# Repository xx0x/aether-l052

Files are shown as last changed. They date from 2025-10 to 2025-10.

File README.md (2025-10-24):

# Æther L052

A development board using the STM32L052K8Ux, optimized for low-power use. Its form factor matches the Adafruit Feather series.

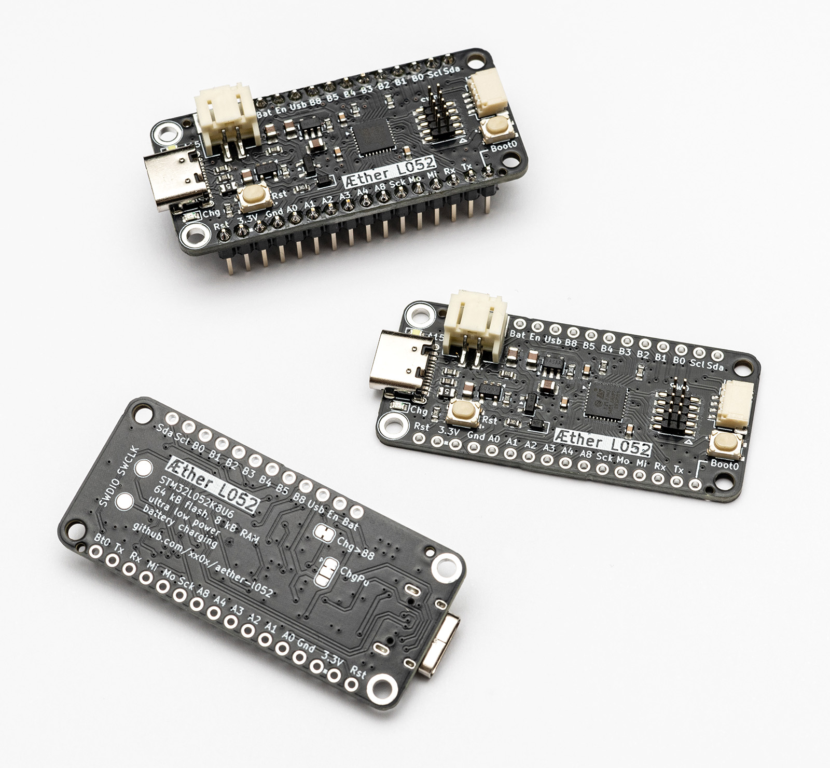
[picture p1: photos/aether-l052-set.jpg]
Aether L052


## Schematic

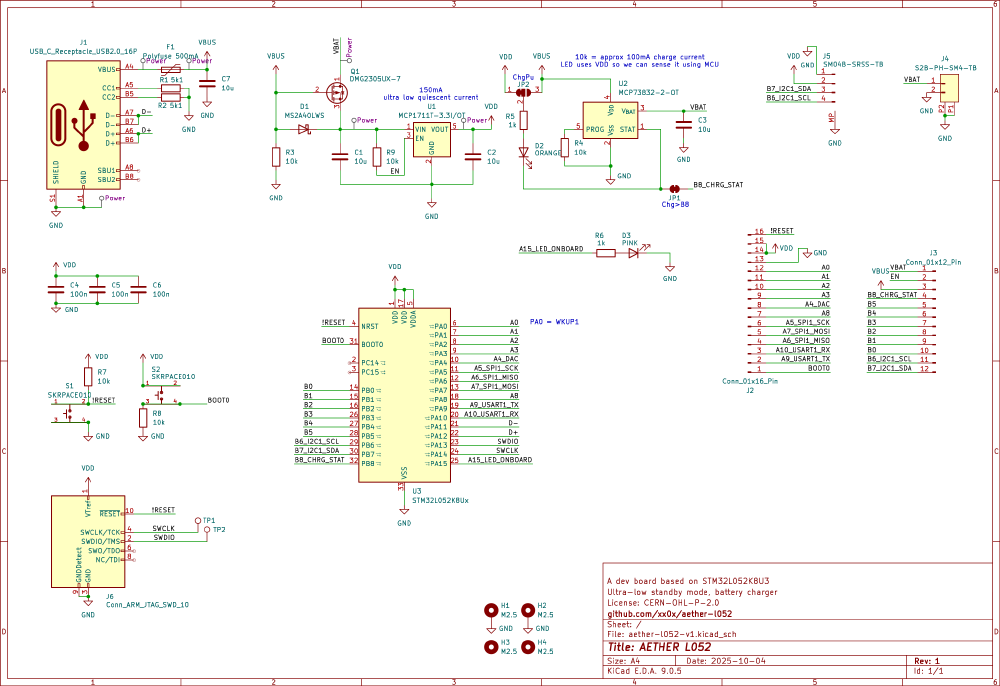
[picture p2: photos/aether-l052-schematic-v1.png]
Aether L052
  
*Click to see the full-size PDF*

## Specifications

### Microcontroller

| Name | STM32L052K8Ux |
| --- | --- |
| Core | ARM Cortex M0+ |
| Flash Size | 64 kB |
| RAM Size | 8 kB |
| Clock Frequency  | 32 MHz |
| Peripherals | USB, SPI, I2C, UART |
| External Crystal | None |

STM32L052K8U6 = –40 to 85 °C  
STM32L052K8U7 = –40 to 105 °C  
STM32L052K8U3 = –40 to 125 °C  

### Voltage Regulator

| Name | MCP1711T-33I/OT |
| --- | --- |
| Output Voltage | 3.3 V |
| Output Current | 150 mA |
| Quiescent Current | 600 nA |

### Lithium Battery Charger

| Name | MCP73832T-2ACI/OT |
| --- | --- |
| Charge Current | 100 mA (set using R4) |
| Charge State | Available through PB8 |

## Why it exists?

There was no entry-level development board for the STM32L052 series, especially for the compact STM32L052K8Ux variant.

## Where to get it?

Æther L052 is open source and not sold in shops. You can build your own; all required files are in the `pcb` folder. If you are a manufacturer, you may reuse the design under the License, or contact me first if you prefer.

## Code examples

Look at the [Æther L052 Examples](https://github.com/xx0x/aether-l052-examples) repository.

## License

CERN-OHL-P-2.0 license

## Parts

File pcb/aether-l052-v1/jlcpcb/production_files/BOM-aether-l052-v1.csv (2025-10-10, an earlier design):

Comment | Designator | Footprint | LCSC | Quantity
100n | C4,C5,C6 | C_0603_1608Metric | C14663 | 3
10k | R3,R4,R7,R8,R9 | R_0603_1608Metric | C25804 | 5
10u | C1,C2,C3,C7 | C_0805_2012Metric | C15850 | 4
1k | R5,R6 | R_0603_1608Metric | C21190 | 2
5k1 | R1,R2 | R_0603_1608Metric | C23186 | 2
Conn_ARM_JTAG_SWD_10 | J6 | PinHeader_2x05_P1.27mm_Vertical_SMD | C41376037 | 1
DMG2305UX-7 | Q1 | SOT-23 | C150470 | 1
MCP1711T-3.3I/OT | U1 | SOT-23-5 | C79527 | 1
MCP73832-2-OT | U2 | SOT-23-5 | C38066 | 1
MS2A40LWS | D1 | D_SOD-323 | C7380001 | 1
ORANGE | D2 | LED_0603_1608Metric | C2286 | 1
PINK | D3 | LED_0603_1608Metric | C2290 | 1
Polyfuse 500mA | F1 | Fuse_0805_2012Metric | C883109 | 1
S2B-PH-SM4-TB | J4 | S2B-PH-SM4-TB_LF__SN_ | C295747 | 1
SKRPACE010 | S1,S2 | SKRPACE010 | C139797 | 2
SM04B-SRSS-TB | J5 | JST_SH_SM04B-SRSS-TB_1x04-1MP_P1.00mm_Horizontal | C160404 | 1
STM32L052K8Ux | U3 | QFN-32-1EP_5x5mm_P0.5mm_EP3.45x3.45mm | C1342049 | 1
USB_C_Receptacle_USB2.0_16P | J1 | USB_C_Receptacle_XKB_U262-16XN-4BVC11 | C393939 | 1

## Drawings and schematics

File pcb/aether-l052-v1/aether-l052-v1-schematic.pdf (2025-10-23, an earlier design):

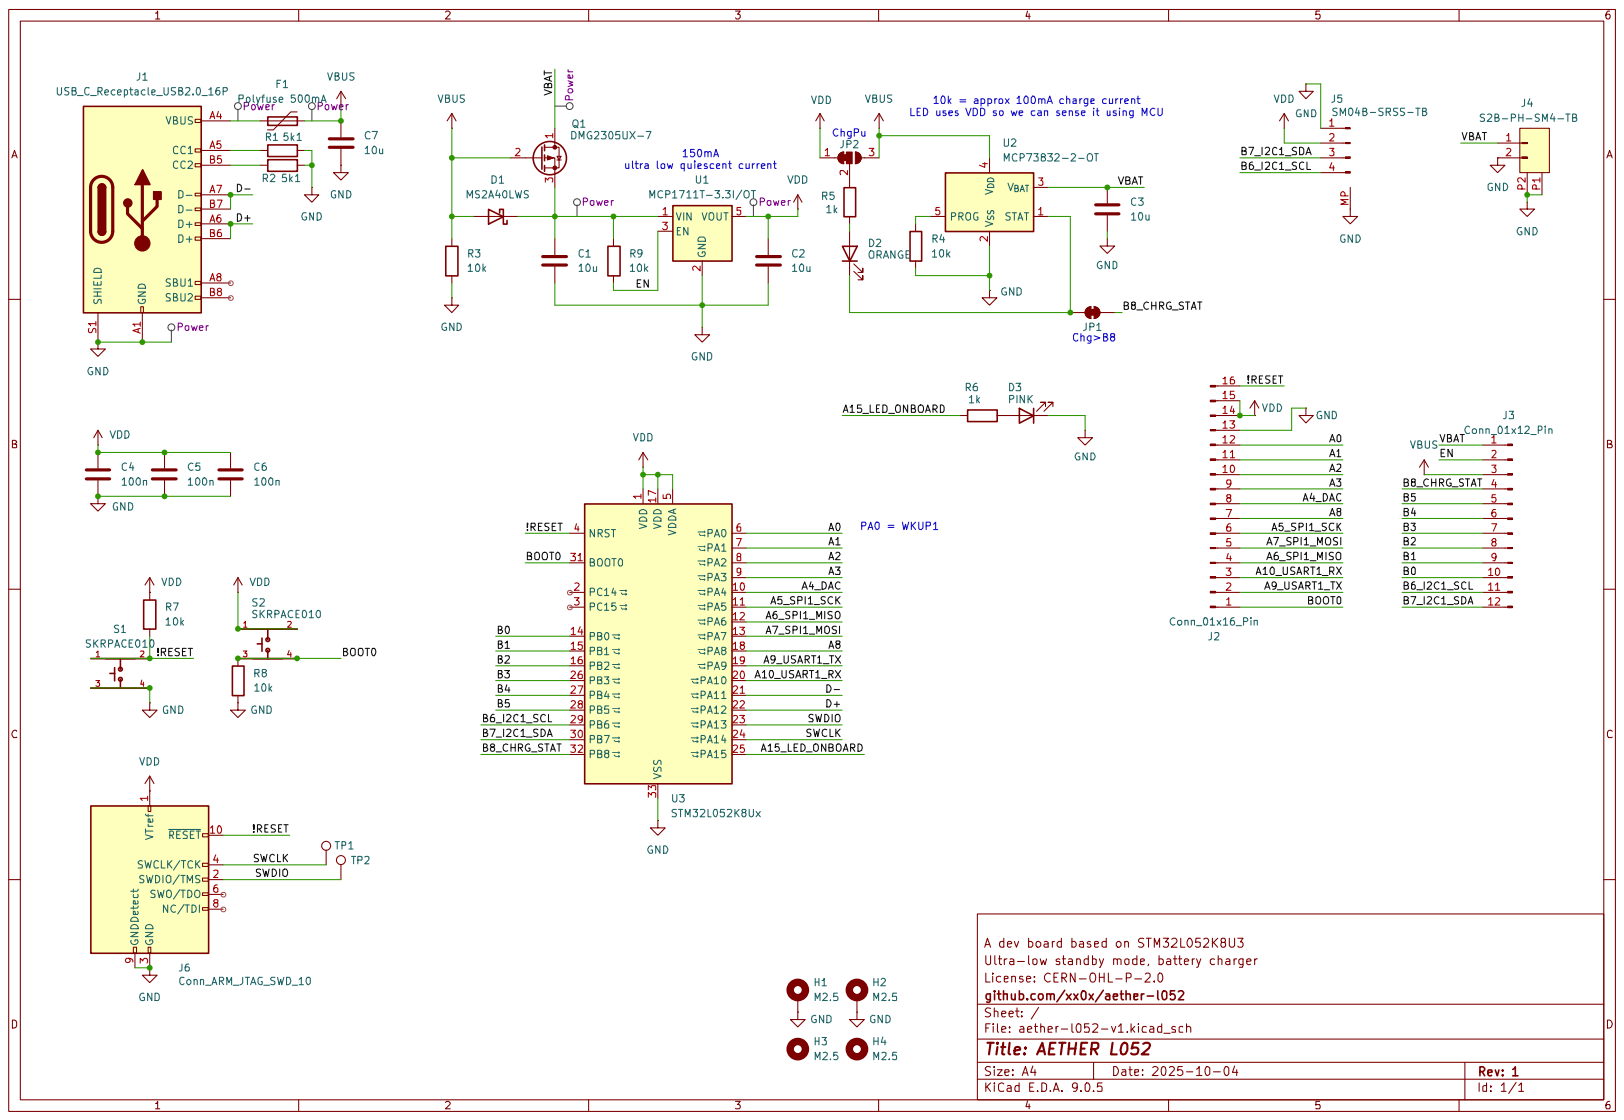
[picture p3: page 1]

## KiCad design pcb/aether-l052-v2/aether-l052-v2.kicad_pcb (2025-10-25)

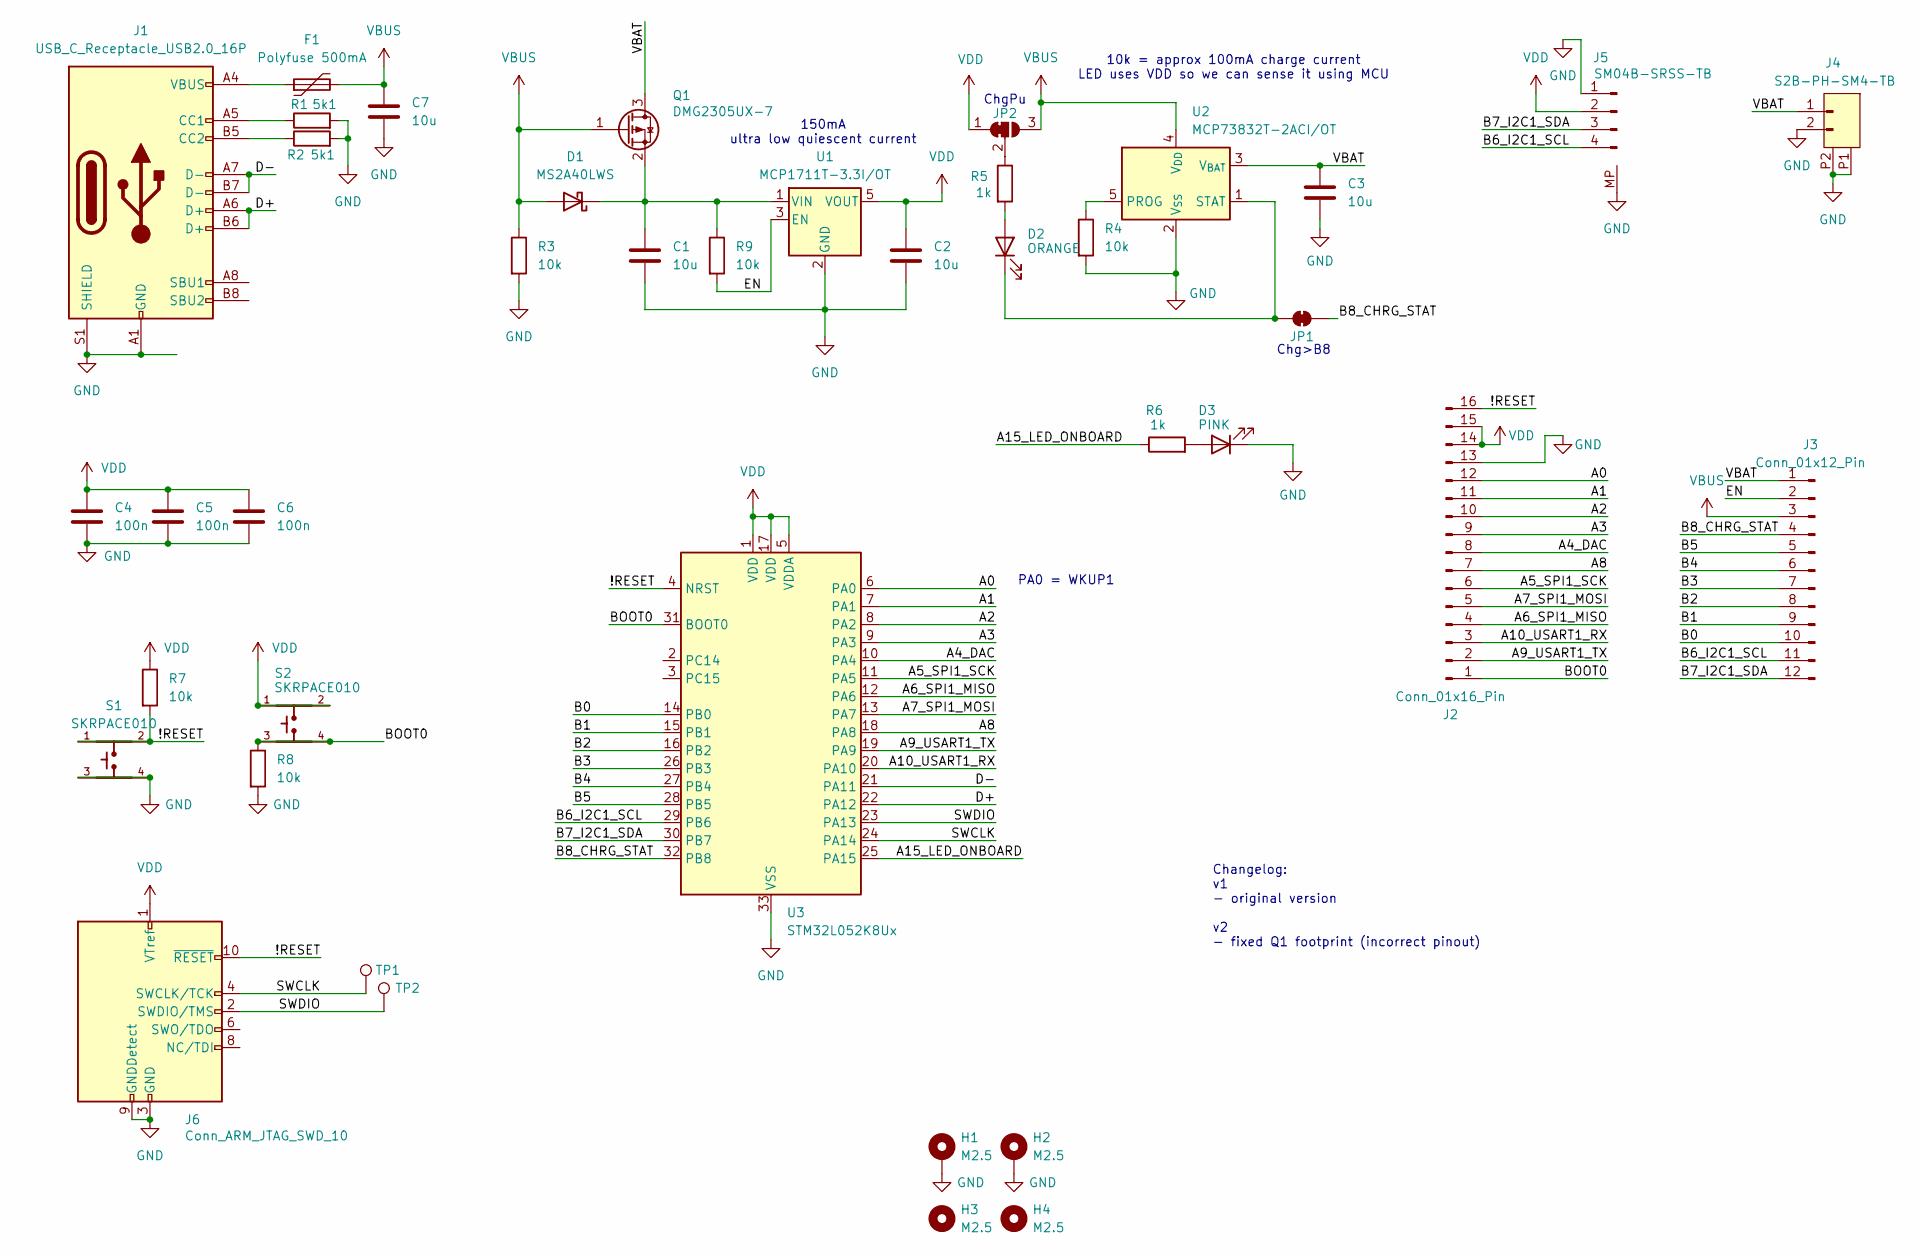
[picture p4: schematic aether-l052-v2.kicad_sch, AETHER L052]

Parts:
C1, C2, C3, C7: 10u; C_0805_2012Metric; LCSC C15850
C4, C5, C6: 100n; C_0603_1608Metric; LCSC C14663
D1: MS2A40LWS; D_SOD-323; LCSC C7380001
D2: ORANGE; LED_0603_1608Metric; LCSC C2286
D3: PINK; LED_0603_1608Metric; LCSC C2290
F1: Polyfuse 500mA; Fuse_0805_2012Metric; LCSC C883109
H1, H2: M2.5; MountingHole_2.5mm_Pad_Small
H3, H4: M2.5; MountingHole_2.5mm
J1: USB_C_Receptacle_USB2.0_16P; USB_C_Receptacle_XKB_U262-16XN-4BVC11; LCSC C393939
J2: Conn_01x16_Pin; PinHeader_1x16_P2.54mm_Vertical_NoSilk
J3: Conn_01x12_Pin; PinHeader_1x12_P2.54mm_Vertical_NoSilk
J4: S2B-PH-SM4-TB; S2B-PH-SM4-TB_LF__SN_; LCSC C295747
J5: SM04B-SRSS-TB; JST_SH_SM04B-SRSS-TB_1x04-1MP_P1.00mm_Horizontal; LCSC C160404
J6: Conn_ARM_JTAG_SWD_10; PinHeader_2x05_P1.27mm_Vertical_SMD; LCSC C41376037
JP1: SolderJumper_2_Bridged; SolderJumper-2_P1.3mm_Bridged_RoundedPad1.0x1.5mm
JP2: SolderJumper_3_Bridged12; SolderJumper-3_P1.3mm_Bridged12_RoundedPad1.0x1.5mm
Q1: DMG2305UX-7; SOT-23
R1, R2: 5k1; R_0603_1608Metric; LCSC C23186
R3, R4, R7, R8, R9: 10k; R_0603_1608Metric; LCSC C25804
R5, R6: 1k; R_0603_1608Metric; LCSC C21190
S1, S2: SKRPACE010; LCSC C139797
TP1: SWCLK; TestPoint_Pad_D2.0mm
TP2: SWDIO; TestPoint_Pad_D2.0mm
U1: MCP1711T-3.3I/OT; SOT-23-5; LCSC C79527
U2: MCP73832T-2ACI/OT; SOT-23-5; LCSC C38066
U3: STM32L052K8Ux; QFN-32-1EP_5x5mm_P0.5mm_EP3.45x3.45mm; LCSC C1342049

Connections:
/!RESET: J2.16, J6.10 (~RESET), R7.2, S1.1, S1.2, U3.4 (NRST)
/A0: J2.12, U3.6 (PA0)
/A1: J2.11, U3.7 (PA1)
/A2: J2.10, U3.8 (PA2)
/A3: J2.9, U3.9 (PA3)
/A4_DAC: J2.8, U3.10 (PA4)
/A5_SPI1_SCK: J2.6, U3.11 (PA5)
/A6_SPI1_MISO: J2.4, U3.12 (PA6)
/A7_SPI1_MOSI: J2.5, U3.13 (PA7)
/A8: J2.7, U3.18 (PA8)
/A9_USART1_TX: J2.2, U3.19 (PA9)
/A10_USART1_RX: J2.3, U3.20 (PA10)
/A15_LED_ONBOARD: R6.1, U3.25 (PA15)
/B0: J3.10, U3.14 (PB0)
/B1: J3.9, U3.15 (PB1)
/B2: J3.8, U3.16 (PB2)
/B3: J3.7, U3.26 (PB3)
/B4: J3.6, U3.27 (PB4)
/B5: J3.5, U3.28 (PB5)
/B6_I2C1_SCL: J3.11, J5.4, U3.29 (PB6)
/B7_I2C1_SDA: J3.12, J5.3, U3.30 (PB7)
/B8_CHRG_STAT: J3.4, JP1.2 (B), U3.32 (PB8)
/BOOT0: J2.1, R8.1, S2.3, S2.4, U3.31 (BOOT0)
/D+: J1.A6 (D+), J1.B6 (D+), U3.22 (PA12)
/D-: J1.A7 (D-), J1.B7 (D-), U3.21 (PA11)
/EN: J3.2, R9.2, U1.3 (EN)
/SWCLK: J6.4 (SWCLK/TCK), TP1.1, U3.24 (PA14)
/SWDIO: J6.2 (SWDIO/TMS), TP2.1, U3.23 (PA13)
/VBAT: C3.1, J3.1, J4.1, Q1.3 (D), U2.3 (V_{BAT})
GND: C1.2, C2.2, C3.2, C4.2, C5.2, C6.2, C7.2, D3.1 (K), H1.1, H2.1, J1.A1 (GND), J1.A12 (GND), J1.B1 (GND), J1.B12 (GND), J1.S1 (SHIELD), J2.13, J4.2, J4.P1, J4.P2, J5.1, J5.MP, J6.3 (GND), J6.5 (GND), J6.9 (GNDDetect), R1.2, R2.2, R3.2, R4.2, R8.2, S1.3, S1.4, U1.2 (GND), U2.2 (V_{SS}), U3.33 (VSS)
unnamed: C1.1, D1.1 (K), Q1.2 (S), R9.1, U1.1 (VIN)
unnamed: D2.2 (A), R5.2
unnamed: D2.1 (K), JP1.1 (A), U2.1 (STAT)
unnamed: D3.2 (A), R6.2
unnamed: F1.1, J1.A4 (VBUS), J1.A9 (VBUS), J1.B4 (VBUS), J1.B9 (VBUS)
unnamed: J1.A5 (CC1), R1.1
unnamed: J1.B5 (CC2), R2.1
unnamed: JP2.2 (C), R5.1
unnamed: R4.1, U2.5 (PROG)
VBUS: C7.1, D1.2 (A), F1.2, J3.3, JP2.3 (B), Q1.1 (G), R3.1, U2.4 (V_{DD})
VDD: C2.1, C4.1, C5.1, C6.1, J2.14, J2.15, J5.2, J6.1 (VTref), JP2.1 (A), R7.1, S2.1, S2.2, U1.5 (VOUT), U3.1 (VDD), U3.5 (VDDA), U3.17 (VDD)

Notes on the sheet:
150mA ultra low quiescent current
ChgPu
Changelog: v1 - original version v2 - fixed Q1 footprint (incorrect pinout)
10k = approx 100mA charge current LED uses VDD so we can sense it using MCU
PA0 = WKUP1
Chg>B8

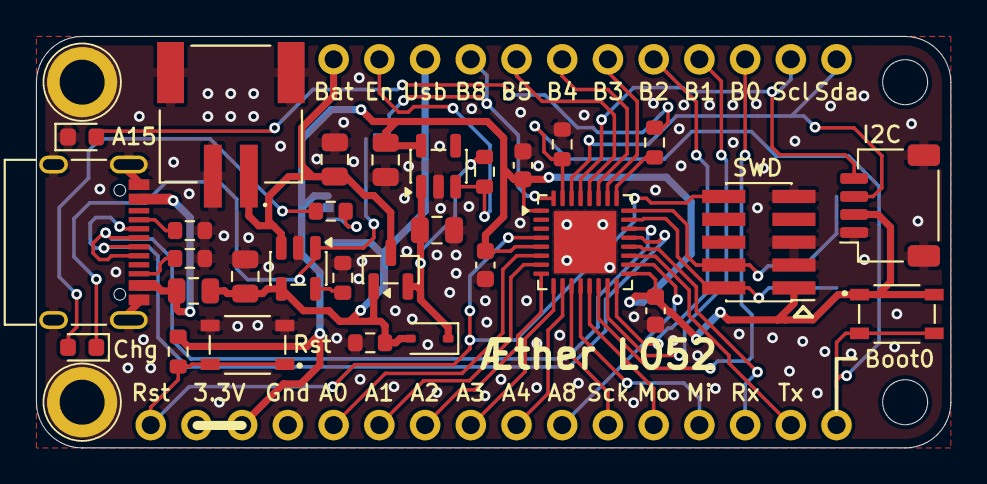
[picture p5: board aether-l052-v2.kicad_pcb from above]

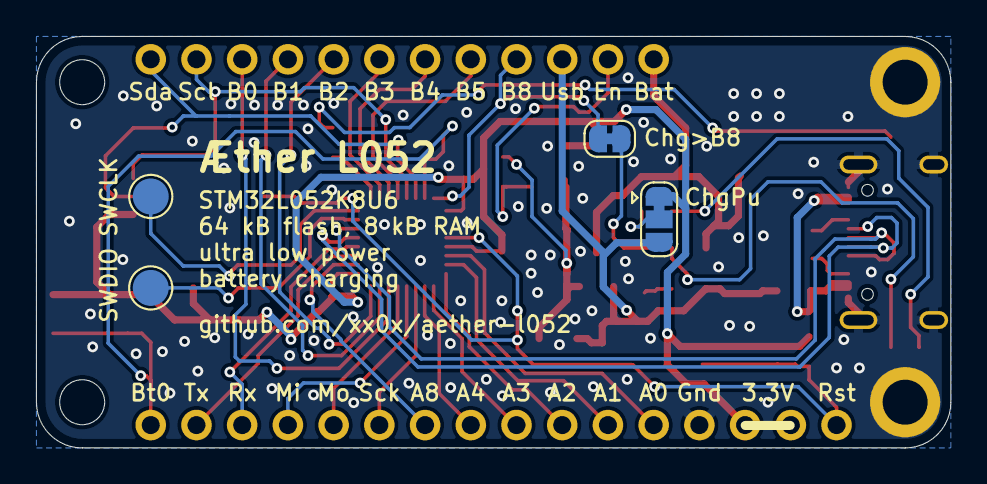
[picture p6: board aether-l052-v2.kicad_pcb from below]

Board: 2 copper layers, 50.8 x 22.9 mm, 40 parts (6 on the bottom side), 41 nets.

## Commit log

2025-10-04 initial sketches
    [aether-l052-v1.kicad_pcb, aether-l052-v1.kicad_sch]
2025-10-05 schematic, board layout in progress
    [aether-l052-v1.kicad_pcb, aether-l052-v1.kicad_sch]
2025-10-10 routing tweaks
    [aether-l052-v1.kicad_pcb, aether-l052-v1.kicad_sch]
2025-10-10 finishing board, add gerber, bom, cpl
    [BOM-aether-l052-v1.csv, aether-l052-v1.kicad_pcb, aether-l052-v1.kicad_sch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]
2025-10-23 add readme and photo
    [aether-l052-v1.kicad_pcb, aether-l052-v1.kicad_sch]
2025-10-24 add temperature ranges, change link
2025-10-25 add v2, fixes
    [aether-l052-v2.kicad_pcb, aether-l052-v2.kicad_sch]
